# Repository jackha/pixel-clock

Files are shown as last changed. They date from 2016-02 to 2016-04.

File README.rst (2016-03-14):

Pixel Clock
-----------

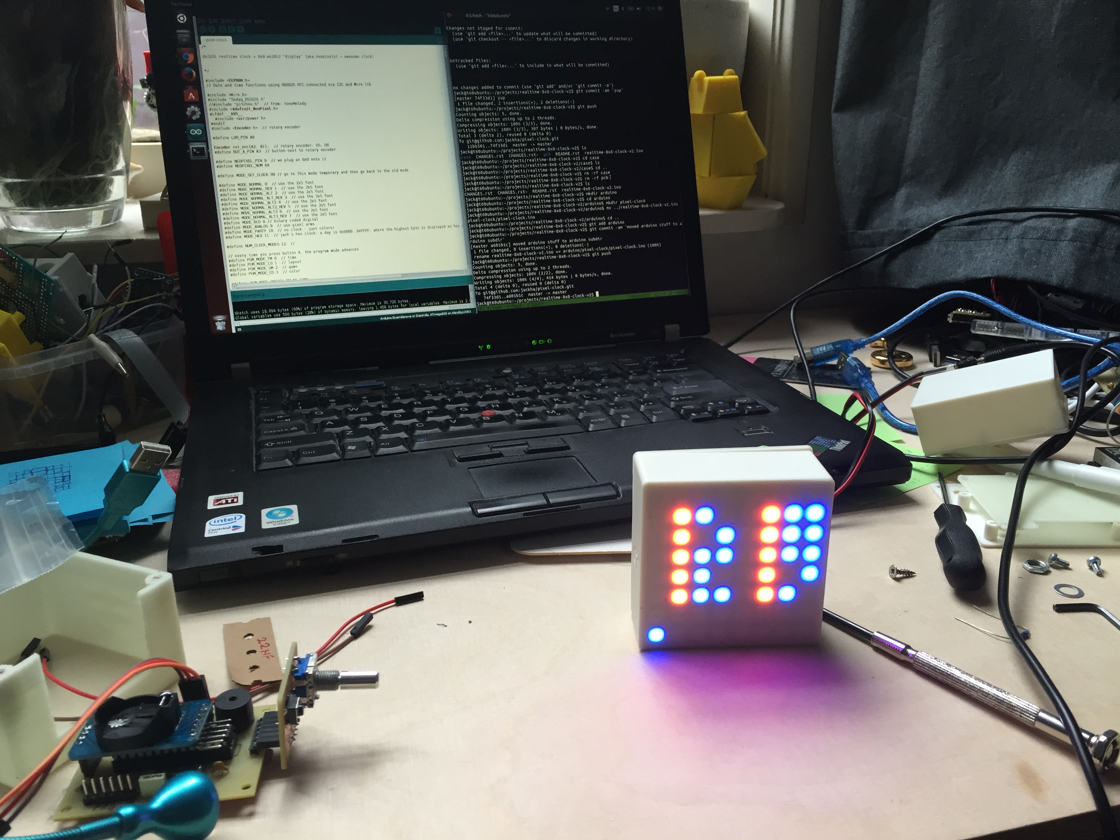
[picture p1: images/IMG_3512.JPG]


A pixel clock with an 8x8 rgb led display based on Arduino.

- Atmega 328 microcontroller
- DS3231 realtime clock module
- ws2812 8x8 LED display aka NeoPixel.
- Control using a rotary encoder /w button.

The case consist of a front and a back part. It is modeled in OpenSCAD.

The pcb is designed in Eagle.

All is work in progress. You can follow the project:

http://jh-interact.blogspot.nl/

http://www.thingiverse.com/thing:1372109

Arduino dependencies
--------------------

Tested and working with these libraries. Many thanks to the authors
for creating and sharing them!!

- Sodaq_DS3231 by keestux, 1.2.0

- Adafruit NeoPixel 1.0.4

- Adafruit GFX Library 1.1.4

- Encoder by Paul Stoffregen 1.4.0

License
-------

Open source hardware and software :-) Please follow my License as I put time
and effort in this project. Thanks!

https://creativecommons.org/licenses/by-nc/3.0/
Attribution-NonCommercial 3.0 Unported (CC BY-NC 3.0)

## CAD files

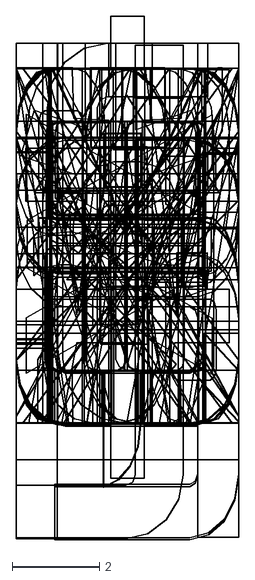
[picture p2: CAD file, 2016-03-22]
case-word-clock/orbitron.dxf
5.08 x 12.0

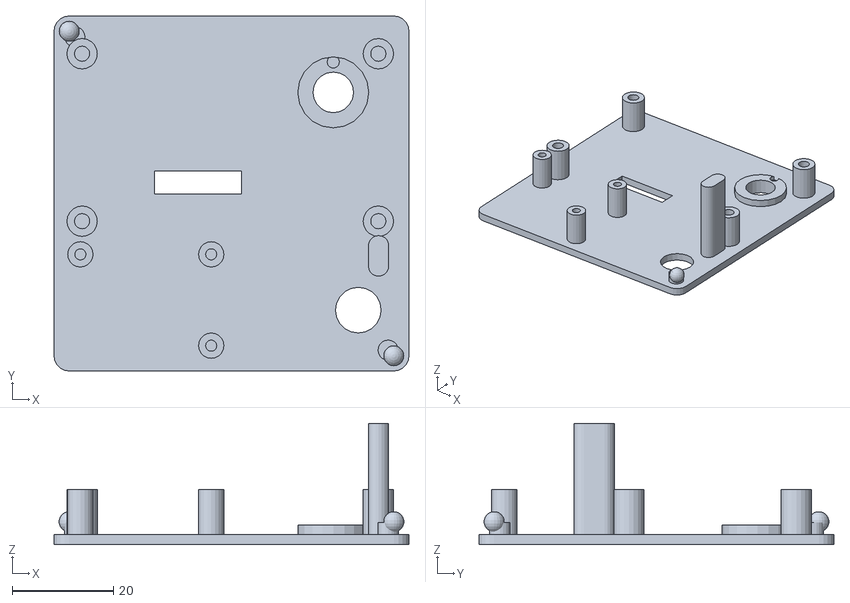
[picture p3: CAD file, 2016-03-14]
case/clock-case3-back.stl
70.0 x 70.0 x 23.9

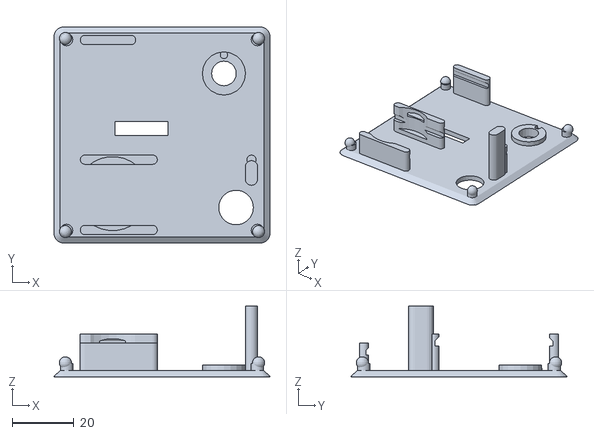
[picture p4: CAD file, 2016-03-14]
case/clock-case4b-07-clearance.stl
70.0 x 70.0 x 22.9

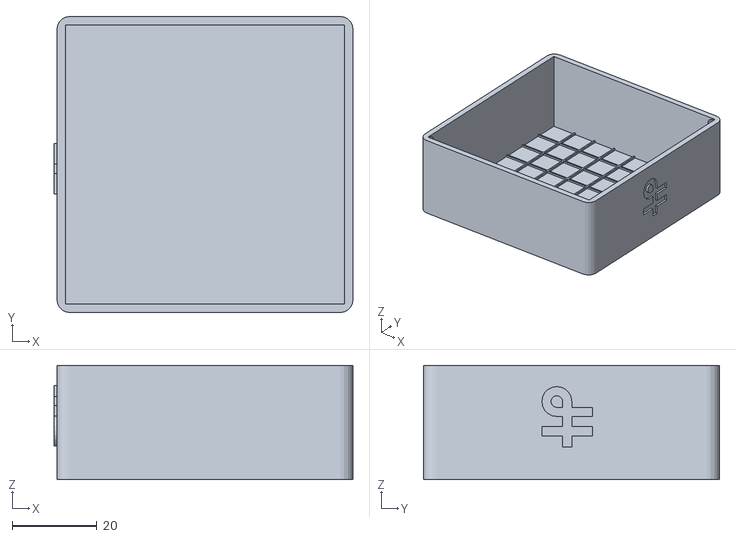
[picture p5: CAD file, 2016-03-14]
case/clock-case3.stl
70.7 x 70.0 x 27.0

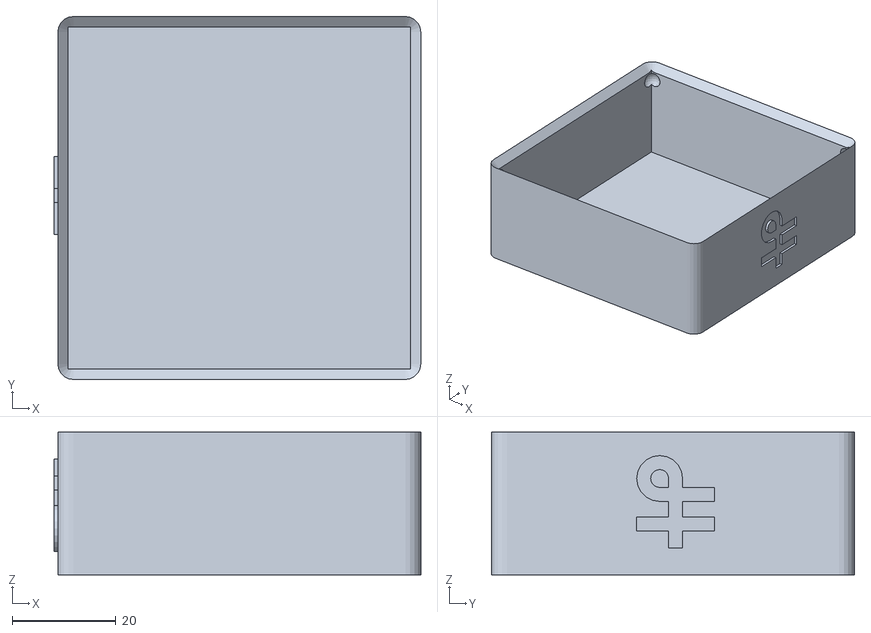
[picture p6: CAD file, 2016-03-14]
case/clock-case4b.stl
70.7 x 70.0 x 27.5

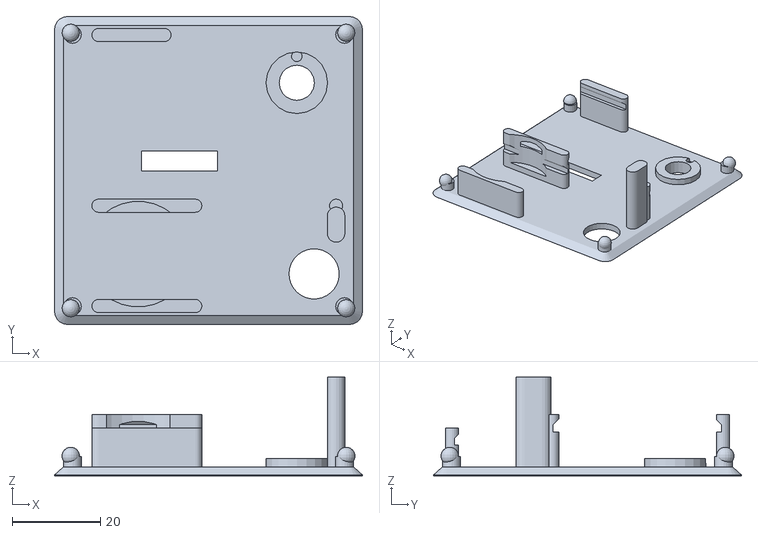
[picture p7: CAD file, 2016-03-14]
case/clock-case4b-back.stl
70.0 x 70.0 x 22.4

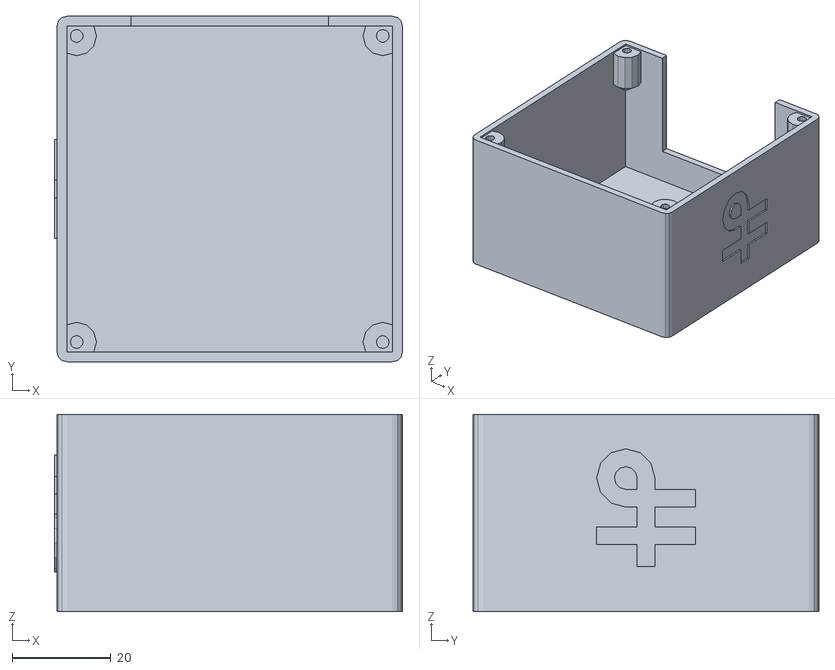
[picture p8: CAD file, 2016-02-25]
case/clock-case.stl
70.5 x 70.0 x 40.0

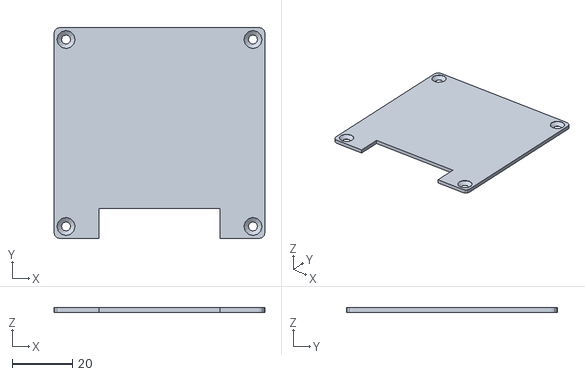
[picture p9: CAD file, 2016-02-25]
case/clock-case-back.stl
70.0 x 70.0 x 1.50

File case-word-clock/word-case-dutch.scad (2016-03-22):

/*
Use this as an extra face plate for the Pixel Clock!
*/

use <Write.scad>

INNER_WIDTH = 70.5;  
INNER_HEIGHT = 70.5;

ROUNDING_R = 4;
ROUNDING_R_INNER = 3;

SIDE_THICKNESS = 1.5;
FRONT_THICKNESS = 1;

OUTER_WIDTH = INNER_WIDTH + 2 * SIDE_THICKNESS;
OUTER_HEIGHT = INNER_HEIGHT + 2 * SIDE_THICKNESS;

DEPTH = 15;

FONT_SIZE = 12;
FONT_SCALE_Y = 0.6;

FONT_X_OFFSET = 4;
FONT_Y_OFFSET = 5;
FONT_Y_SPACING = 8;

LETTERS = [
    "VIJFVOOR", "OVERHALF", "TWEEAALF", "NEGENEEN",
    "DRIEVIER", "VIJFZZES", "ZEVENELF", "ACHTIENZ"];

module rounded_cube(x, y, z, r) {
    translate([r,r,0])
    minkowski() {
        cube([x-2*r, y-2*r, 1]);
        cylinder(r=r, h=z-1);
    }
}

module rounded_cube2(x, y, z, r, x2, y2, r2) {
    hull() {
        translate([r,r,0])
        minkowski() {
            cube([x-2*r, y-2*r, 0.1]);
            cylinder(r=r, h=0.1);
        }

        translate([r2-(x2-x)/2,r2-(y2-y)/2,z-0.2])
        minkowski() {
            cube([x2-2*r2, y2-2*r2, 0.1]);
            cylinder(r=r2, h=0.1);
        }
    
    }
}

difference() {
    rounded_cube(
        OUTER_WIDTH, OUTER_HEIGHT, DEPTH, ROUNDING_R); 

    translate([SIDE_THICKNESS, SIDE_THICKNESS, FRONT_THICKNESS])
    rounded_cube(
        INNER_WIDTH, INNER_HEIGHT, DEPTH, ROUNDING_R_INNER); 

    *rounded_cube2(
        OUTER_WIDTH, OUTER_HEIGHT, DEPTH, ROUNDING_R, 
        INNER_WIDTH, INNER_HEIGHT, ROUNDING_R_INNER);
    
    for (y=[0:7]) {
        translate([OUTER_WIDTH-FONT_X_OFFSET,FONT_Y_OFFSET+y*FONT_Y_SPACING,-0.1])
        mirror([-1,0,0])
        scale([1, FONT_SCALE_Y, 1])
        write(LETTERS[7-y],t=5, h=FONT_SIZE, center=false, font="orbitron.dxf");
    }
}

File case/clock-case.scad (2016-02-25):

use <logo.scad>;

$fn = 12;

SIDE_THICKNESS = 2;
FRONT_THICKNESS = 0.5;
BACK_THICKNESS = 1.5;
DEPTH = 40;

INNER_WIDTH = 66;
OUTER_WIDTH = INNER_WIDTH + 2*SIDE_THICKNESS;
INNER_HEIGHT = 66;
OUTER_HEIGHT = INNER_HEIGHT + 2*SIDE_THICKNESS;

ROUNDING_R = 2;

HOLDER_OUTER_R = 4;
HOLDER_INNER_R = 1.3;
HOLDER_H = 10;

module rounded_cube(x, y, z, r) {
    translate([r,r,0])
    minkowski() {
        cube([x-2*r, y-2*r, 1]);
        cylinder(r=r, h=z-1);
    }
}

module tapped_hole(h1, h2, r1, r2) {
    cylinder(r=r1, h=h1);
    translate([0,0,h1-0.1])
    cylinder(r1=r1, r2=r2, h=h2);
    translate([0,0,h1+h2-0.1])
    cylinder(r=r2, h=10);
}

module base() {
union() {
difference() {
    rounded_cube(OUTER_WIDTH, OUTER_HEIGHT, DEPTH, ROUNDING_R);
    
    translate([SIDE_THICKNESS, SIDE_THICKNESS, FRONT_THICKNESS])
    cube([INNER_WIDTH, INNER_HEIGHT, DEPTH]);
    
    translate([OUTER_WIDTH/2-20, 60, 10])
    cube([40, 50, DEPTH]);

    translate([OUTER_WIDTH - 0.5, OUTER_HEIGHT/2-10, 33])
    rotate([0,90,0])
    logo(5, 20);
}

    translate([2-0.5, OUTER_HEIGHT/2-10, 8])
    rotate([0,-90,0])
    logo(2, 20);

    difference() {
        hull() {
            translate([SIDE_THICKNESS-0.1, SIDE_THICKNESS-0.1, 25])
            cylinder(r=0.1, h=1);
            translate([HOLDER_OUTER_R, HOLDER_OUTER_R, DEPTH-HOLDER_H-0.5])
            cylinder(r=HOLDER_OUTER_R, h=HOLDER_H);
        }
        translate([HOLDER_OUTER_R, HOLDER_OUTER_R, DEPTH-HOLDER_H])
        cylinder(r=HOLDER_INNER_R, h=100);
    }
    difference() {
        hull() {
            translate([OUTER_WIDTH-SIDE_THICKNESS+0.1, SIDE_THICKNESS-0.1, 25])
            cylinder(r=0.1, h=1);
            translate([OUTER_WIDTH-HOLDER_OUTER_R, HOLDER_OUTER_R, DEPTH-HOLDER_H-0.5])
            cylinder(r=HOLDER_OUTER_R, h=HOLDER_H);
        }
        translate([OUTER_WIDTH-HOLDER_OUTER_R, HOLDER_OUTER_R, DEPTH-HOLDER_H])
        cylinder(r=HOLDER_INNER_R, h=100);
    }
    difference() {
        hull() {
            translate([SIDE_THICKNESS-0.1, OUTER_HEIGHT-SIDE_THICKNESS+0.1, 25])
            cylinder(r=0.1, h=1);
            translate([HOLDER_OUTER_R, OUTER_HEIGHT-HOLDER_OUTER_R, DEPTH-HOLDER_H-0.5])
            cylinder(r=HOLDER_OUTER_R, h=HOLDER_H);
        }
        translate([HOLDER_OUTER_R, OUTER_HEIGHT-HOLDER_OUTER_R, DEPTH-HOLDER_H])
        cylinder(r=HOLDER_INNER_R, h=100);
    }
    difference() {
        hull() {
            translate([OUTER_HEIGHT-SIDE_THICKNESS+0.1, OUTER_HEIGHT-SIDE_THICKNESS+0.1, 25])
            cylinder(r=0.1, h=1);
            translate([OUTER_WIDTH-HOLDER_OUTER_R, OUTER_HEIGHT-HOLDER_OUTER_R, DEPTH-HOLDER_H-0.5])
            cylinder(r=HOLDER_OUTER_R, h=HOLDER_H);
        }
        translate([OUTER_WIDTH-HOLDER_OUTER_R, OUTER_HEIGHT-HOLDER_OUTER_R, DEPTH-HOLDER_H])
        cylinder(r=HOLDER_INNER_R, h=100);
    }
    
}
}

SCREW_R1 = 1.5;
SCREW_R2 = 3;

module back() {
   difference() {
        rounded_cube(OUTER_WIDTH, OUTER_HEIGHT, BACK_THICKNESS, ROUNDING_R);
       
       translate([OUTER_WIDTH/2-20, -1, -1])
       cube([40, 11, 10]);
            
       translate([HOLDER_OUTER_R, HOLDER_OUTER_R, -1])
       tapped_hole(r1=SCREW_R1, r2=SCREW_R2, h1=1.2, h2=1.3);

       translate([HOLDER_OUTER_R, OUTER_HEIGHT-HOLDER_OUTER_R, -1])
       tapped_hole(r1=SCREW_R1, r2=SCREW_R2, h1=1.2, h2=1.3);

       translate([OUTER_WIDTH-HOLDER_OUTER_R, HOLDER_OUTER_R, -1])
       tapped_hole(r1=SCREW_R1, r2=SCREW_R2, h1=1.2, h2=1.3);

       translate([OUTER_WIDTH-HOLDER_OUTER_R, OUTER_HEIGHT-HOLDER_OUTER_R, -1])
       tapped_hole(r1=SCREW_R1, r2=SCREW_R2, h1=1.2, h2=1.3);

   }
}

//base();
back();

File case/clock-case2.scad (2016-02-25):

use <logo.scad>;

$fn = 20;

SIDE_THICKNESS = 2;
FRONT_THICKNESS = 0.5;
BACK_THICKNESS = 2;
DEPTH = 27;

INNER_WIDTH = 66;
OUTER_WIDTH = INNER_WIDTH + 2*SIDE_THICKNESS;
INNER_HEIGHT = 66;
OUTER_HEIGHT = INNER_HEIGHT + 2*SIDE_THICKNESS;

ROUNDING_R = 2;

HOLDER_OUTER_R = 4;
HOLDER_INNER_R = 1.3;
HOLDER_H = 10;

module rounded_cube(x, y, z, r) {
    translate([r,r,0])
    minkowski() {
        cube([x-2*r, y-2*r, 1]);
        cylinder(r=r, h=z-1);
    }
}

module tapped_hole(h1, h2, r1, r2) {
    cylinder(r=r1, h=h1);
    translate([0,0,h1-0.1])
    cylinder(r1=r1, r2=r2, h=h2);
    translate([0,0,h1+h2-0.1])
    cylinder(r=r2, h=10);
}

module base() {
union() {
difference() {
    rounded_cube(OUTER_WIDTH, OUTER_HEIGHT, DEPTH, ROUNDING_R);
    
    translate([SIDE_THICKNESS, SIDE_THICKNESS, FRONT_THICKNESS])
    cube([INNER_WIDTH, INNER_HEIGHT, DEPTH]);
    
    translate([OUTER_WIDTH - 0.7, OUTER_HEIGHT/2-7, 22])
    rotate([0,90,0])
    logo(5, 12);
}

    translate([2-0.7, OUTER_HEIGHT/2-7, 8])
    rotate([0,-90,0])
    logo(2, 12);

    difference() {
        hull() {
            translate([SIDE_THICKNESS-0.1, SIDE_THICKNESS-0.1, 25])
            cylinder(r=0.1, h=1);
            translate([HOLDER_OUTER_R, HOLDER_OUTER_R, DEPTH-HOLDER_H-0.5])
            cylinder(r=HOLDER_OUTER_R, h=HOLDER_H);
        }
        translate([HOLDER_OUTER_R, HOLDER_OUTER_R, DEPTH-HOLDER_H])
        cylinder(r=HOLDER_INNER_R, h=100);
    }
    *difference() {
        hull() {
            translate([OUTER_WIDTH-SIDE_THICKNESS+0.1, SIDE_THICKNESS-0.1, 25])
            cylinder(r=0.1, h=1);
            translate([OUTER_WIDTH-HOLDER_OUTER_R, HOLDER_OUTER_R, DEPTH-HOLDER_H-0.5])
            cylinder(r=HOLDER_OUTER_R, h=HOLDER_H);
        }
        translate([OUTER_WIDTH-HOLDER_OUTER_R, HOLDER_OUTER_R, DEPTH-HOLDER_H])
        cylinder(r=HOLDER_INNER_R, h=100);
    }
    *difference() {
        hull() {
            translate([SIDE_THICKNESS-0.1, OUTER_HEIGHT-SIDE_THICKNESS+0.1, 25])
            cylinder(r=0.1, h=1);
            translate([HOLDER_OUTER_R, OUTER_HEIGHT-HOLDER_OUTER_R, DEPTH-HOLDER_H-0.5])
            cylinder(r=HOLDER_OUTER_R, h=HOLDER_H);
        }
        translate([HOLDER_OUTER_R, OUTER_HEIGHT-HOLDER_OUTER_R, DEPTH-HOLDER_H])
        cylinder(r=HOLDER_INNER_R, h=100);
    }
    *difference() {
        hull() {
            translate([OUTER_HEIGHT-SIDE_THICKNESS+0.1, OUTER_HEIGHT-SIDE_THICKNESS+0.1, 25])
            cylinder(r=0.1, h=1);
            translate([OUTER_WIDTH-HOLDER_OUTER_R, OUTER_HEIGHT-HOLDER_OUTER_R, DEPTH-HOLDER_H-0.5])
            cylinder(r=HOLDER_OUTER_R, h=HOLDER_H);
        }
        translate([OUTER_WIDTH-HOLDER_OUTER_R, OUTER_HEIGHT-HOLDER_OUTER_R, DEPTH-HOLDER_H])
        cylinder(r=HOLDER_INNER_R, h=100);
    }


    // holder
        hull() {
            translate([OUTER_HEIGHT-SIDE_THICKNESS+0.1, OUTER_HEIGHT-SIDE_THICKNESS+0.1, DEPTH-3-2])
            cylinder(r=0.1, h=2);
            translate([OUTER_HEIGHT-SIDE_THICKNESS-1, OUTER_HEIGHT-SIDE_THICKNESS-1, DEPTH-1-2])
            cylinder(r=2, h=1);
        }

        hull() {
            translate([OUTER_HEIGHT-SIDE_THICKNESS-1, OUTER_HEIGHT-SIDE_THICKNESS-1, DEPTH-1-2])
            cylinder(r=2, h=1);
            translate([OUTER_HEIGHT-SIDE_THICKNESS+0.1, OUTER_HEIGHT-SIDE_THICKNESS+0.1, DEPTH-2])
            cylinder(r=0.1, h=2);
        }
    
}
}

SCREW_R1 = 1.5;
SCREW_R2 = 3;


MOUNT_SCREW_R = 1.5;  // for base pcb
MOUNT_SCREW_OUTER_R = 3;

MOUNT_SCREW_R2 = 1.1;  // for rtc module
MOUNT_SCREW_OUTER_R2 = 2.5;  // for rtc module

module mounting_tube(h) {
    difference() {
        cylinder(r=MOUNT_SCREW_OUTER_R, h=h);
        translate([0,0,-1])
        cylinder(r=MOUNT_SCREW_R, h=h+2);
    }
}

module pcb_mounting_tubes(h) {
    translate([0.1*25.4, 0.1*25.4, 0])
    mounting_tube(h);

    translate([2.4*25.4, 0.1*25.4, 0])
    mounting_tube(h);

    translate([0.1*25.4, 1.4*25.4, 0])
    mounting_tube(h);

    translate([2.4*25.4, 1.4*25.4, 0])
    mounting_tube(h);

    translate([(2.5-0.45) * 25.4, 1.1*25.4, 0])
    cylinder(r=7, h=2);
}

PRG_MARGIN = 1;

module pcb_holes() {
    translate([(2.5-0.45) * 25.4, 1.1*25.4, -10])
    cylinder(r=4, h=50);

    translate([(2.5-0.45) * 25.4, 1.1*25.4 + 6, 2-1])
    cylinder(r=1.2, h=2);

    translate([0.7 * 25.4-PRG_MARGIN, 0.35*25.4-PRG_MARGIN, -10])
    cube([0.6*25.4+2*PRG_MARGIN, 2.54+2*PRG_MARGIN, 15]);
}

module mounting_tube_rtc(h) {
    difference() {
        cylinder(r=MOUNT_SCREW_OUTER_R2, h=h);
        translate([0,0,-1])
        cylinder(r=MOUNT_SCREW_R2, h=h+2);
    }
}

module rtc_mounts(h) {
    translate([-4, 2, 0])
    mounting_tube_rtc(h);

    translate([-29.8, 20, 0])
    mounting_tube_rtc(h);

    translate([-4, 20, 0])
    mounting_tube_rtc(h);
}

HOOK_R = 2;

module back() {
   difference() {
       union() {
           rounded_cube(OUTER_WIDTH, OUTER_HEIGHT, BACK_THICKNESS, ROUNDING_R);
           
           translate([3,27,BACK_THICKNESS-0.1])
           pcb_mounting_tubes(9);

            // support for display
            hull() {
           translate([64,24.7,BACK_THICKNESS-0.1])
           cylinder(r=2, h=DEPTH-5);
           translate([64,20.7,BACK_THICKNESS-0.1])
           cylinder(r=2, h=DEPTH-5);
            }
                
           translate([35,3,BACK_THICKNESS-0.1])
           rtc_mounts(9);

           // corner hook thing
            translate([0.3,-0.3,0])  // allow some clearance for touching side
            difference() {

           translate([HOOK_R+SIDE_THICKNESS+0.1, OUTER_HEIGHT-HOOK_R-SIDE_THICKNESS-0.1, BACK_THICKNESS-0.1])
           cylinder(r=HOOK_R, h=9);

        union() {
        hull() {
            translate([SIDE_THICKNESS-0.1, OUTER_HEIGHT-SIDE_THICKNESS+0.1, BACK_THICKNESS])
            cylinder(r=0.1, h=2);
            translate([SIDE_THICKNESS+1, OUTER_HEIGHT-SIDE_THICKNESS-1, BACK_THICKNESS+2])
            cylinder(r=2, h=1);
        }

        hull() {
            
            translate([SIDE_THICKNESS+1, OUTER_HEIGHT-SIDE_THICKNESS-1, BACK_THICKNESS+2])
            cylinder(r=2, h=1);
               
        translate([SIDE_THICKNESS-0.1, OUTER_HEIGHT-SIDE_THICKNESS+0.1, BACK_THICKNESS+3+1])
            cylinder(r=.1, h=2);
        
            }
        }
       }
   } // union
       
       translate([3,27,BACK_THICKNESS-0.1])
       pcb_holes();
       
       //pwr connector
       translate([60,12,-1])
       cylinder(r=4.5,h=10);
       
        // screw hole
       translate([0,0,1.3])
       mirror([0,0,1])
       translate([OUTER_WIDTH-HOLDER_OUTER_R, HOLDER_OUTER_R, -1])
       tapped_hole(r1=SCREW_R1, r2=SCREW_R2, h1=1.2, h2=1.3);

   }
}

//base();
back();

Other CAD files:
case/clock-case2.stl
case/clock-case2-back.stl
case/clock-case3.scad
case-word-clock/Write.scad
case/clock-case4b.scad
case/knob.scad
case/logo.scad

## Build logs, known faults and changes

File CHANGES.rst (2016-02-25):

v2
--

- Added OpenSCAD files for the case

- Added eagle files version 3p.

- Use eeprom to save and load

  - layout mode

  - used colors

- Better colors

- A lot of user friendlyness.

- hex clock

- party mode

- a single button + rotary encoder

v1
--

- Set colors.

- Able to set clock on the interface.

- Prototype game (Frogger).

- BCD clock

- 'Normal' numeric clock

- Modes: TM (time), LO (layout), GM (game), CO (color)

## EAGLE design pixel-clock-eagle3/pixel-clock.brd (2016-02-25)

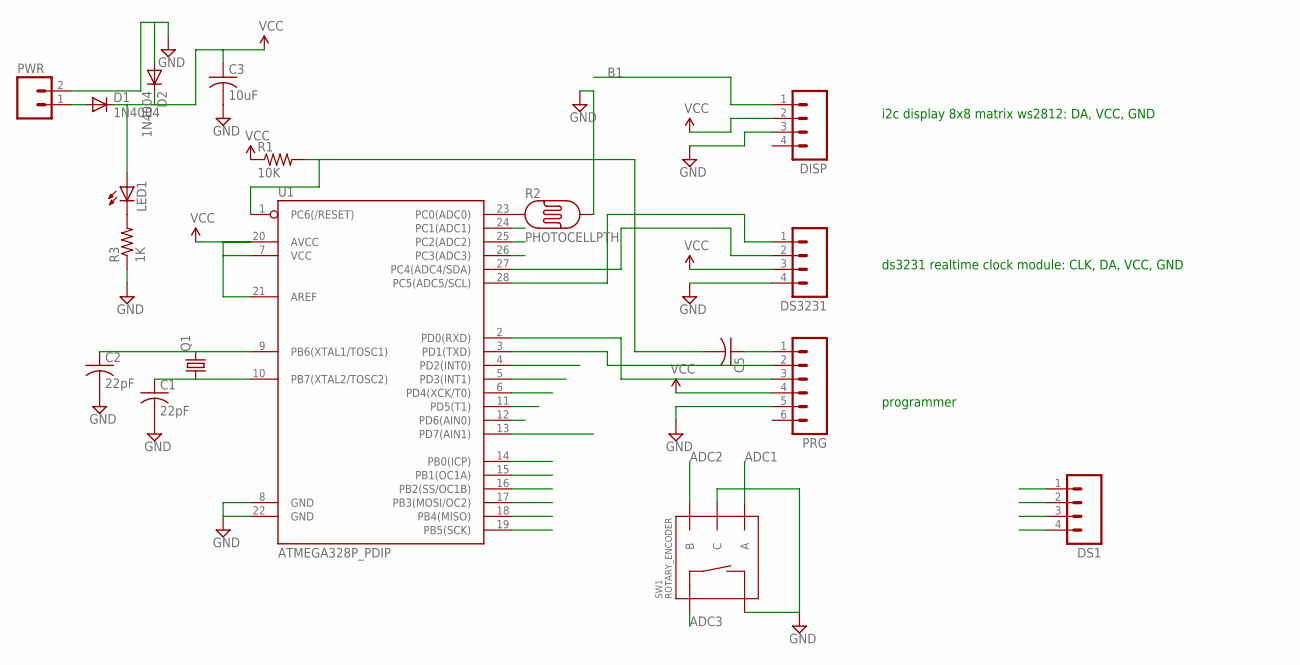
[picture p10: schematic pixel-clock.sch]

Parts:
C1, C2: 22pF; C050-024X044
C3: 10uF; C025-025X050
C5: C-US025-025X050; C025-025X050
D1, D2: 1N4004; DO41-10
DISP: M04PTH; 1X04
DS1, DS3231: M04PTH; 1X04
LED1: LED3MM
PRG: M06SILK_FEMALE_PTH; 1X06
PWR: M02PTH3; 1X02_LONGPADS
Q1: CRYSTALHC49S; HC49/S
R1: 10K; 0207/9
R2: PHOTOCELLPTH; PHOTOCELL
R3: 1K; 0207/9
SW1: ROTARY_ENCODER; ROTARY_ENC_PLAIN
U1: ATMEGA328P_PDIP; DIL28-3

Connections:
ADC1: SW1.A, U1.24 (PC1(ADC1))
ADC2: SW1.B, U1.25 (PC2(ADC2))
ADC3: SW1.SW+, U1.26 (PC3(ADC3))
B0: DS1.1, U1.14 (PB0(ICP))
B1: DISP.1, U1.15 (PB1(OC1A))
B2: U1.16 (PB2(SS/OC1B))
B3: U1.17 (PB3(MOSI/OC2))
B4: U1.18 (PB4(MISO))
B5: U1.19 (PB5(SCK))
D0: PRG.3, U1.2 (PD0(RXD))
D1: PRG.2, U1.3 (PD1(TXD))
D2: U1.4 (PD2(INT0))
D3: U1.5 (PD3(INT1))
D4: U1.6 (PD4(XCK/T0))
D5: U1.11 (PD5(T1))
D6: DS1.3, U1.12 (PD6(AIN0))
D7: DS1.2, U1.13 (PD7(AIN1))
GND: C1.2, C2.2, C3.2, D2.A, DISP.3, DS1.4, DS3231.4, PRG.5, PWR.2, R2.2, R3.1, SW1.C, SW1.SW-, U1.8 (GND), U1.22 (GND)
unnamed: DS3231.1, U1.28 (PC5(ADC5/SCL))
unnamed: DS3231.2, U1.27 (PC4(ADC4/SDA))
unnamed: R2.1, U1.23 (PC0(ADC0))
unnamed: C2.1, Q1.2, U1.9 (PB6(XTAL1/TOSC1))
unnamed: C1.1, Q1.1, U1.10 (PB7(XTAL2/TOSC2))
unnamed: D1.A, PWR.1
unnamed: LED1.K (C), R3.2
unnamed: C5.1, PRG.1
unnamed: C5.2, R1.2, U1.1 (PC6(/RESET))
VCC: C3.1, D1.C, D2.C, DISP.2, DS3231.3, LED1.A, PRG.4, R1.1, U1.7 (VCC), U1.20 (AVCC), U1.21 (AREF)

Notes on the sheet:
i2c display 8x8 matrix ws2812: DA, VCC, GND
ds3231 realtime clock module: CLK, DA, VCC, GND
programmer

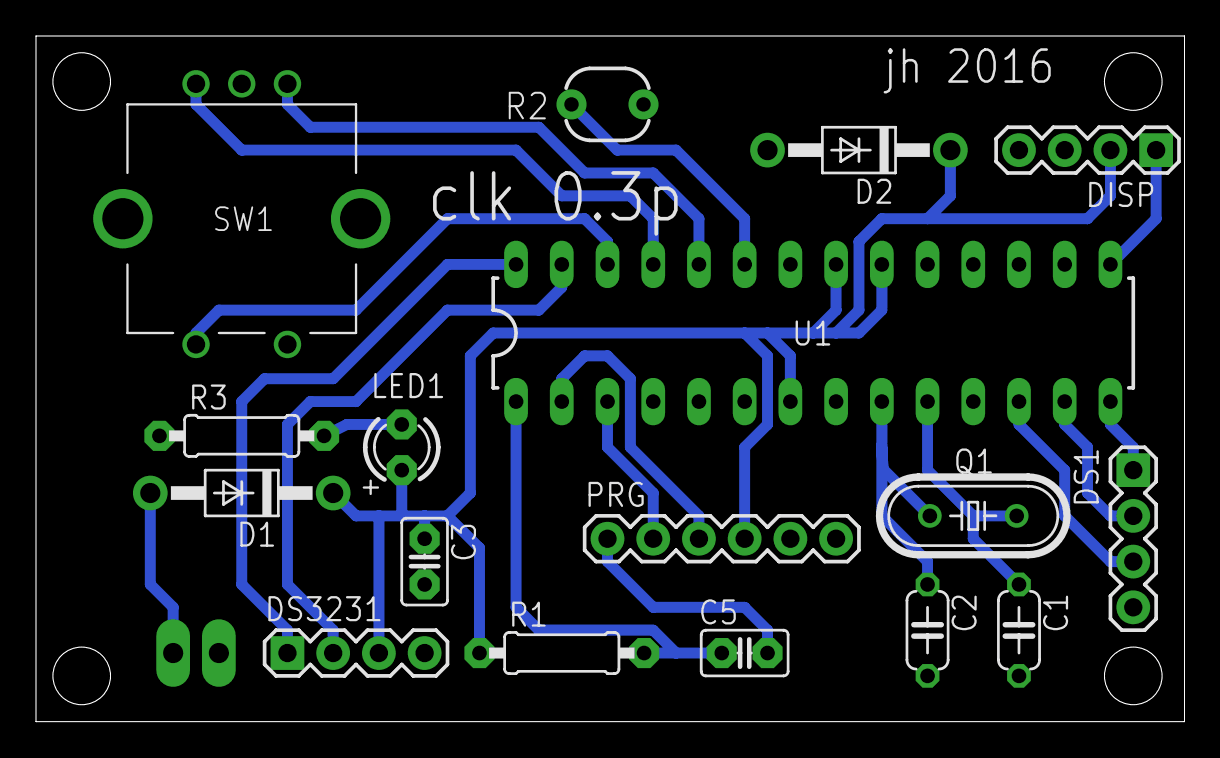
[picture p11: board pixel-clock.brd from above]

Board: 2 copper layers, 63.8 x 38.1 mm, 18 parts (0 on the bottom side), 20 nets.

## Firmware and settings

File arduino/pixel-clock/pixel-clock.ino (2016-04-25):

/*

ds3231 realtime clock + 8x8 ws2812 "display" (aka neopixels) = awesome clock!


*/

#include "font.h"
#include "bitmap.h"
#include "table.h"

#include <EEPROM.h>

// Date and time functions using RX8025 RTC connected via I2C and Wire lib
#include <Wire.h>
#include "Sodaq_DS3231.h"
//#include "pitches.h"  // from: toneMelody
#include <Adafruit_NeoPixel.h>
#ifdef __AVR__
  #include <avr/power.h>
#endif
#include <Encoder.h>  // rotary encoder

#define LDR_PIN A0

Encoder rot_enc(A2, A1);  // rotary encoder: D5, D6
#define BUT_A_PIN A3  // button next to rotary encoder

#define NEOPIXEL_PIN 9  // we plug an 8x8 onto it
#define NEOPIXEL_NUM 64

#define MODE_SET_CLOCK 99 // go to this mode temporary and then go back to the old mode 

#define MODE_NORMAL 0  // use the 2x5 font
#define MODE_NORMAL_REV 1  // use the 2x5 font
#define MODE_NORMAL_ALT 2  // use the 2x5 font
#define MODE_NORMAL_ALT_REV 3  // use the 2x5 font
#define MODE_NORMAL_ALT2 4  // use the 2x5 font
#define MODE_NORMAL_ALT2_REV 5  // use the 2x5 font
#define MODE_NORMAL_ALT3 6  // use the 2x5 font
#define MODE_NORMAL_ALT3_REV 7  // use the 2x5 font
#define MODE_BCD 8 // binary coded digital 
#define MODE_ANALOG 9  // use pixel arms
#define MODE_PARTY 10  // no clock - just colors!
#define MODE_HEX 11  // jack's hex clock: a day is 0x0000..0xFFFF, where the highest byte is displayed as hex and lowest as bits
#define MODE_GAME_OF_LIFE 12  // conways game of life
#define MODE_4X4 13  // conways game of life
#define MODE_WORD 14  // word clock
#define MODE_ROBOT 15

#define NUM_CLOCK_MODES 16  //

// every time you press button A, the program mode advances
#define PGM_MODE_TM 0  // time
#define PGM_MODE_LO 1  // layout
#define PGM_MODE_GM 2  // game
#define PGM_MODE_CO 3  // color
#define PGM_MODE_BR 4  // brightness

#define PGM_MODE_TE 5  // tetris

#define PGM_MODE_SWITCH_DELAY 1000

// in tm mode, every b press advances the time edit mode
#define PGM_TM_NONE 0
#define PGM_TM_HOUR 1
#define PGM_TM_MINUTE 2

#ifdef __AVR__
 #include <avr/io.h>
 #include <avr/pgmspace.h>
#elif defined(ESP8266)
 #include <pgmspace.h>
#else
 #define PROGMEM
#endif

struct RGB {
   byte   r;
   byte   g;
   byte   b;

   byte h;  // hue, for memory purposes only
   byte s;  // saturation
   byte l;  // luminosity
};

struct RGB col_a; 
struct RGB col_b; 

long enc_pos  = -999;  // rotary encoder position
// for colors
long neg_enc_pos  = -999;  // rotary encoder position
long pos_enc_pos  = -999;  // rotary encoder position
volatile long new_enc_pos = -999;
volatile long old_enc_pos = -999;  // detection of movement
uint16_t fast_counter = 0;  // just cycles, for use in timing / moving stuff other than seconds

unsigned long start_approx_millis_time = 0;
unsigned long approx_millis = 0;  // approximate millis

// game of life in RGB! 0 is current buffer, 1 is future
byte game_of_life[2][3*64];

Adafruit_NeoPixel pixels = Adafruit_NeoPixel(NEOPIXEL_NUM, NEOPIXEL_PIN, NEO_GRB + NEO_KHZ800);


char weekDay[][4] = {"Sun", "Mon", "Tue", "Wed", "Thu", "Fri", "Sat" };
//year, month, date, hour, min, sec and week-day(starts from 0 and goes to 6)
//writing any non-existent time-data may interfere with normal operation of the RTC.
//Take care of week-day also.
//DateTime dt(2016, 2, 10, 15, 18, 0, 5);


// notes in the melody:
int melody[] = {
//  NOTE_C4, NOTE_G3, NOTE_G3, NOTE_A3, NOTE_G3, 0, NOTE_B3, NOTE_C4
   35, 100, 200, 60, 32, 76, 250, 0
};

// note durations: 4 = quarter note, 8 = eighth note, etc.:
int noteDurations[] = {
  4, 8, 8, 4, 4, 4, 4, 4
};

int clock_mode = MODE_NORMAL;
int last_clock_mode = MODE_NORMAL;
int pgm_mode = PGM_MODE_LO;

int pgm_mode_tm_state = PGM_TM_NONE;
int hour_inc = 0;  // increase/decrease hour because we want to change it - is auto modded (%)
int minute_inc = 0;

int last_but_a_val = HIGH;
int last_but_b_val = HIGH;
int but_a_val = HIGH;
int but_b_val = HIGH;
int but_counter = 0;

int color_idx = 0;
int tmp_int;

uint16_t ldr_value;
uint16_t brightness;
uint16_t brightness_offset;
int brightness_target;

uint32_t last_action_ts;  // when was the last action? too long -> go back to layout mode

#define TETRIS_SIZE_X 8
#define TETRIS_SIZE_Y 10
byte tetris_playfield[TETRIS_SIZE_Y*TETRIS_SIZE_X]; // we use the 'tetris index' below for its contents, 255 is empty.


#define TETRIS_I 0
#define TETRIS_J 1
#define TETRIS_L 2
#define TETRIS_O 3
#define TETRIS_S 4
#define TETRIS_T 5
#define TETRIS_Z 6
#define TETRIS_EMPTY 255

// RGB colors in order of appearance
static const unsigned char tetris_colors[] PROGMEM = {
  0x00, 0xff, 0xff,  // I, cyan
  0xff, 0x00, 0x00,  // J, blue
  0xff, 0x80, 0x00,  // L, orange
  0xff, 0xff, 0x00,  // O, yellow
  0x00, 0xff, 0x00,  // S, green
  0xa0, 0x20, 0xf0,  // T, purple
  0xff, 0x00, 0x00,  // Z, red
};

static const unsigned char tetris_blocks[] PROGMEM = {
// I
  0b0000,
  0b1111,
  0b0000,
  0b0000,

  0b0010,
  0b0010,
  0b0010,
  0b0010,

  0b0000,
  0b0000,
  0b1111,
  0b0000,

  0b0100,
  0b0100,
  0b0100,
  0b0100,

// J
  0b1000,
  0b1110,
  0b0000,
  0b0000,

  0b0110,
  0b0100,
  0b0100,
  0b0000,

  0b0000,
  0b1110,
  0b0010,
  0b0000,

  0b0100,
  0b0100,
  0b1100,
  0b0000,

// L
  0b0100,
  0b0100,
  0b0110,
  0b0000,

  0b0000,
  0b1110,
  0b1000,
  0b0000,

  0b1100,
  0b0100,
  0b0100,
  0b0000,

  0b0010,
  0b1110,
  0b0000,
  0b0000,
// O
  0b0110,
  0b0110,
  0b0000,
  0b0000,

  0b0110,
  0b0110,
  0b0000,
  0b0000,

  0b0110,
  0b0110,
  0b0000,
  0b0000,

  0b0110,
  0b0110,
  0b0000,
  0b0000,

// S
  0b0110,
  0b1100,
  0b0000,
  0b0000,

  0b0100,
  0b0110,
  0b0010,
  0b0000,

  0b0000,
  0b0110,
  0b1100,
  0b0000,

  0b1000,
  0b1100,
  0b0100,
  0b0000,

// T
  0b0100,
  0b1110,
  0b0000,
  0b0000,

  0b0100,
  0b0110,
  0b0100,
  0b0000,

  0b0000,
  0b1110,
  0b0100,
  0b0000,

  0b0100,
  0b1100,
  0b0100,
  0b0000,

// Z
  0b1100,
  0b0110,
  0b0000,
  0b0000,

  0b0010,
  0b0110,
  0b0100,
  0b0000,

  0b0000,
  0b1100,
  0b0110,
  0b0000,

  0b0100,
  0b1100,
  0b1000,
  0b0000,
};

void reset_tetris() {
  for (int y=0; y<TETRIS_SIZE_Y; y++) {
    for (int x=0; x<TETRIS_SIZE_X; x++) {
      tetris_playfield[y*TETRIS_SIZE_X+x] = TETRIS_EMPTY;
    }
  }
}

// block 0..6, rotation 0..3
// return true if collision or out of bounds, false if ok
boolean tetris_check_collision(int x_, int y_, int block, int rotation) {
  byte tetromino_row;
  int tetromino_offset = block*16 + (rotation % 4)*4;
  byte xx, yy;
  for (int y=0; y<4; y++) {
    tetromino_row = pgm_read_byte(tetris_blocks+tetromino_offset+y);
    for (int x=0; x<4; x++) {
      if ((tetromino_row & 0b1) > 0) {
        xx = 3 - x + x_;
        yy = y + y_;
        if ((xx >= 0) && (xx < TETRIS_SIZE_X) && (yy >= 0) && (yy < TETRIS_SIZE_Y)) {
          //set_pixel(xx + yy * 8, r, g, b, brightness);
          if (tetris_playfield[yy*TETRIS_SIZE_X+xx] != TETRIS_EMPTY) {
            return true;
          }
        } else {
          return true;  // one of the blocks is out of bounds
        }
      }
      tetromino_row = tetromino_row >> 1;
    }
  }
  return false;
}

// display playfield, special function for 8x8 display
// hope this is fast
void tetris_display(int x_offset, int y_offset, int brightness) {
  byte r, g, b;
  byte tetromino;
  for (int y=0; y<8; y++) {
    for (int x=0; x<8; x++) {
      tetromino = tetris_playfield[(y+y_offset)*8+x+x_offset];
      if (tetromino != TETRIS_EMPTY) {
        r = pgm_read_byte(tetris_colors + 3 * tetromino + 0);
        g = pgm_read_byte(tetris_colors + 3 * tetromino + 1);
        b = pgm_read_byte(tetris_colors + 3 * tetromino + 2);

        set_pixel(y*8+x, r, g, b, brightness);  
      }
    }
  }
}

// just 'plot' the piece in place, no collision check
void tetris_place_tetromino(int x_, int y_, int block, int rotation) {
  byte tetromino_row;
  int tetromino_offset = block*16 + (rotation % 4)*4;
  byte xx, yy;
  for (int y=0; y<4; y++) {
    tetromino_row = pgm_read_byte(tetris_blocks+tetromino_offset+y);
    for (int x=0; x<4; x++) {
      if ((tetromino_row & 0b1) > 0) {
        xx = 3 - x + x_;
        yy = y + y_;
        if ((xx >= 0) && (xx < TETRIS_SIZE_X) && (yy >= 0) && (yy < TETRIS_SIZE_Y)) {
          tetris_playfield[yy*TETRIS_SIZE_X+xx] = block;
        }
      }
      tetromino_row = tetromino_row >> 1;
    }
  }  
}

void tetris() {
  reset_tetris();
  int block = TETRIS_S;
  int rotation = 1;
  int x = 3;
  int y = 0;
  boolean game_over = false;
  long int current_millis = millis();
  long int next_move_millis;
  int block_duration = 500;

  int but_a_val, last_but_a_val;
  long int enc_pos;
  rot_enc.write(0);

  while (!game_over) {
    block = (block + 1) % 7;  // TODO: implement "Random Generator"
    rotation = (rotation + 1) % 4;
    x = 3-rotation;
    y = 0;
    game_over = tetris_check_collision(x, y+1, block, rotation) && (y == 0);
    next_move_millis = current_millis + block_duration;
    while (!tetris_check_collision(x, y+1, block, rotation)) {
      pixels.clear();
      // provide offset of playfield and brightness
      tetris_display(0, 2, 100);
      // convert playfield coordinates to screen coordinates
      display_tetromino(x, y-2, block, rotation, 100);  
      pixels.show();
      current_millis = millis();
      if (current_millis > next_move_millis) {
        y += 1;
        next_move_millis = current_millis + block_duration;
      }
      // game controls
      last_but_a_val = but_a_val;
      but_a_val = digitalRead(BUT_A_PIN);
      enc_pos = new_enc_pos / 4;
      if ((enc_pos < 0) && (!tetris_check_collision(x-1, y, block, rotation))) {
        x -= 1;
        rot_enc.write(0);
      }
      if ((enc_pos > 0) && (!tetris_check_collision(x+1, y, block, rotation))) {
        x += 1;
        rot_enc.write(0);
      }
      if (
        (but_a_val == LOW) && 
        (last_but_a_val == HIGH) && 
        (!tetris_check_collision(x+1, y, block, (rotation + 1) % 4))) {
          
        rotation = (rotation + 1) % 4;
      }
    }
    tetris_place_tetromino(x, y, block, rotation);
    // TODO: check for full lines and shift all
  }
  delay(1000);
}

ISR(TIMER1_COMPA_vect){  //change the 0 to 1 for timer1 and 2 for timer2
    new_enc_pos = rot_enc.read();
}

void setup () 
  {

  cli();//stop interrupts


//set timer1 interrupt at 16*10^6/1024/11
  TCCR1A = 0;// set entire TCCR1A register to 0
  TCCR1B = 0;// same for TCCR1B
  TCNT1  = 0;//initialize counter value to 0
  // set compare match register for 8MHz increments
  OCR1A = 10;// (must be <65536)
  // turn on CTC mode
  TCCR1B |= (1 << WGM12);
  // Set prescaler CS10, CS11 CS12
  //TCCR1B |= (1 << CS10);  // no prescaling  
  //TCCR1B |= (1 << CS11);  // /8  
  //TCCR1B |= (1 << CS10) + (1 << CS11);  // /64  
  //TCCR1B |= (1 << CS12);  // 256  
  TCCR1B |= (1 << CS10) | (1 << CS12);  // 1024  
  //TCCR1B |= (1 << CS12) | (1 << CS11);  // external clock on t1 pin, falling edge
  //TCCR1B |= (1 << CS12) | (1 << CS11) |  (1 << CS10);  // external clock on t1 pin, rising edge
  // enable timer compare interrupt
  TIMSK1 |= (1 << OCIE1A);
  sei();//allow interrupts

    pinMode(BUT_A_PIN, INPUT_PULLUP);
    //pinMode(BUT_B_PIN, INPUT_PULLUP);

    pinMode(LDR_PIN, INPUT_PULLUP);

    Serial.begin(57600);
    
    Wire.begin();
    rtc.begin();
    pixels.begin();

    but_a_val = digitalRead(BUT_A_PIN);
    last_but_a_val = but_a_val;

    read_eeprom();
      rot_enc.write(4*clock_mode);
  // prevent readouts on start
  new_enc_pos = rot_enc.read();
  enc_pos = new_enc_pos;

  init_game_of_life();  

  last_action_ts = rtc.now().getEpoch(); 

// testing tetris stuff
//
//  for (int b=0; b<7; b++) {
//  for (int y=-4; y<9; y++) {
//    pixels.clear();
//   display_tetromino(3, y, b*16 + (y/4)*4, 100);
////   display_tetromino(4, 0, TETRIS_Z + 1*4, 100);
////   display_tetromino(0, 4, TETRIS_I + 0*4, 100);
////   display_tetromino(4, 4, TETRIS_O + 2*4, 100);
//   delay(100);
//   pixels.show();
//  }
//  }
//  delay(1000);
  tetris();
}

uint32_t old_ts;

/***************************************************************************/


void display_big_bitmap(int location_offset_x, int location_offset_y, int bitmap_offset, 
  byte r1, byte g1, byte b1,
  byte r2, byte g2, byte b2,
  byte r3, byte g3, byte b3) 
  {
  byte pixels_value, pix_value;
  byte xx, yy;
  byte r, g, b;
  
  // screen coords
  for (int y=0; y<8; y++) {
    for (int x=0; x<8; x++) {
        // image source location
        xx = x + location_offset_x;
        yy = y + location_offset_y;

        if ((xx < 0) || (xx > 31) || (yy < 0) || (yy > 7)) {
          continue;
        }
        // is slightly inefficient, because most bytes are fetched 4 times, oh well
        pixels_value = pgm_read_byte(big_bitmaps+bitmap_offset+yy*8+xx/4);  
        pix_value = (pixels_value >> (2* (3 - xx % 4))) & 0b11;
        switch(pix_value) {
          case 0:
            //r = r0; g=g0; b=b0; break;
            continue; break;
          case 1:
            r = r1; g=g1; b=b1; break;
          case 2:
            r = r2; g=g2; b=b2; break;
          case 3:
            r = r3; g=g3; b=b3; break;          
        }
        set_pixel(y * 8 + x, r, g, b, brightness);
    }
  }
}


/***************************************************************************/
// normal clock with digits from 'font'
void draw_normal_clock(DateTime dt, RGB col_a, RGB col_b, int y0, int y1, int y2, int y3, int dot_location) {
  draw_single_digit(0, y0, dt.hour() / 10, col_a.r, col_a.g, col_a.b);
  draw_single_digit(2, y1, dt.hour() % 10, col_b.r, col_b.g, col_b.b);
  draw_single_digit(4, y2, dt.minute() / 10, col_a.r, col_a.g, col_a.b);
  draw_single_digit(6, y3, dt.minute() % 10, col_b.r, col_b.g, col_b.b);
  if (dt.second() % 2 == 0) {
    set_pixel(dot_location, col_b.r,col_b.g,col_b.b, brightness);
  }
}
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
void loop () 
{
    DateTime now = rtc.now(); //get the current date-time
    uint32_t ts = now.getEpoch();
    byte pix_trans;
    if (ts != old_ts) {
       start_approx_millis_time = millis();
    }
    approx_millis = millis() - start_approx_millis_time;
    if ((ts - last_action_ts) > 300) {
      // go back to default program mode
      pgm_mode = PGM_MODE_LO;
    }
    if (old_enc_pos != new_enc_pos) {
      // detection of movement
      old_enc_pos = new_enc_pos;
    }

    last_but_a_val = but_a_val;
    but_a_val = digitalRead(BUT_A_PIN);

    ldr_value = analogRead(LDR_PIN);
    //Serial.println(ldr_value);
    // offset of a different LDR
    brightness_target = 600 - int(float(ldr_value) * 0.9) + brightness_offset;
    if (brightness < max(brightness_target, 10)) {
    //if (brightness < max(1023 - ldr_value, 10)) {
      brightness++;
    } else {
      brightness--;
    }
    //Serial.println(max(600 - int(float(ldr_value) * 0.9) + brightness_offset, 10));
    //brightness = 50;  // for taking pictures only!!!

      // button down = entering time set mode
      if (but_a_val == LOW) {
          last_action_ts = ts;
          but_counter += 1;

//          // straight transition
//          pixels.setPixelColor((but_counter-50)/3, pixels.Color(0,5,0));
//          pixels.show();

          for (int i=0; i<64; i++) {
            pix_trans = pgm_read_byte(fill_pattern+i+FILL_PATTERN_1);
            if (pix_trans <= (but_counter-50)/3) {
              pixels.setPixelColor(i, pixels.Color(0,5,0));
            }
          }
          pixels.show();

          if (but_counter > 191+50) {   // approx 2 second press
            if (clock_mode == MODE_SET_CLOCK) {
              // cancel clock set
              clock_mode = last_clock_mode;
              pgm_mode = PGM_MODE_LO;
              pgm_mode_tm_state = PGM_TM_NONE;
              rot_enc.write(0);
              display_bitmap(BITMAP_NO, 4, 0, 0);
            } else {
              // enter set clock
              last_clock_mode = clock_mode;
              clock_mode = MODE_SET_CLOCK;
              pgm_mode = PGM_MODE_TM;
              pgm_mode_tm_state = PGM_TM_HOUR;
              rot_enc.write(now.hour()*4);
              new_enc_pos = now.hour()*4;
              hour_inc = now.hour();
              minute_inc = 0;
              enc_pos = new_enc_pos;
              display_bitmap(BITMAP_TM, 0, 4, 0);
            }
            wait_button_up();
          }
      } else {
            but_counter = 0;
      }

      switch (pgm_mode) {
        case PGM_MODE_TM:  // set time
          if ((last_but_a_val == LOW) && (but_a_val == HIGH)) {  // wait until the button is released
            DateTime dt;
            switch (pgm_mode_tm_state) {
              case PGM_TM_HOUR:
                pgm_mode_tm_state = PGM_TM_MINUTE;
                // save hour
                dt = DateTime(now.year(), now.month(), now.date(), hour_inc, now.minute(), now.second(), now.dayOfWeek());
                rtc.setDateTime(dt); //Adjust date-time as defined 'dt' above 
                rot_enc.write(now.minute()*4);
                new_enc_pos = now.minute()*4;
                minute_inc = now.minute();
                hour_inc = 0;  // it is set now
                //enc_pos = new_enc_pos;
                break;
              case PGM_TM_MINUTE:
                pgm_mode_tm_state = PGM_TM_NONE;
                clock_mode = last_clock_mode;
                // save minute
                dt = DateTime(now.year(), now.month(), now.date(), now.hour(), minute_inc, now.second(), now.dayOfWeek());
                rtc.setDateTime(dt); //Adjust date-time as defined 'dt' above 

                pgm_mode = PGM_MODE_LO;
                display_bitmap(BITMAP_OK, 0, 4, 0);
                delay(PGM_MODE_SWITCH_DELAY);
                pgm_mode_tm_state = PGM_TM_NONE;
                rot_enc.write(0);

                break;
            }
          }
          // encoder readout
          switch (pgm_mode_tm_state) {
            case PGM_TM_HOUR:
              if (new_enc_pos < 0) {
                new_enc_pos += 24*4;
                rot_enc.write(new_enc_pos);
              }
              if (new_enc_pos >= 24*4) {
                new_enc_pos -= 24*4;
                rot_enc.write(new_enc_pos);
              }
              hour_inc = new_enc_pos / 4;                
              break;
            case PGM_TM_MINUTE:
              if (new_enc_pos < 0) {
                new_enc_pos += 60*4;
                rot_enc.write(new_enc_pos);
              }
              if (new_enc_pos >= 60*4) {
                new_enc_pos -= 60*4;
                rot_enc.write(new_enc_pos);
              }
              minute_inc = new_enc_pos / 4;                 
              break;
          }
          break;
        case PGM_MODE_LO:
          // encoder readout
          if (new_enc_pos < 0) {
            new_enc_pos += 4*NUM_CLOCK_MODES;
            rot_enc.write(new_enc_pos);
          }
          clock_mode = (new_enc_pos / 4) % NUM_CLOCK_MODES;
          // button a readout
          if ((last_but_a_val == LOW) && (but_a_val == HIGH)) {
            write_eeprom();
            // go to color mode
            pgm_mode = PGM_MODE_CO;
            rot_enc.write(col_b.h + 256 * (255-col_b.s) / 64);  // calculate the encoder position back from current colors
            enc_pos = new_enc_pos;
            pos_enc_pos = col_b.h + 256 * (255-col_b.s) / 64;
            neg_enc_pos = -col_a.h - 256 * (255-col_a.s) / 64;
            display_colors();
            delay(PGM_MODE_SWITCH_DELAY);
          }
          break;
//        case PGM_MODE_GM:
//          // encoder readout
//          if (new_enc_pos != enc_pos) {
//            game();
//            wait_button_up();
//            rot_enc.write(0);
//            enc_pos = 0;
//            new_enc_pos = 0;
//          }
//          // button a readout
//          if ((last_but_a_val == LOW) && (but_a_val == HIGH)) {
//            pgm_mode = PGM_MODE_CO;
//            rot_enc.write(0);
//            enc_pos = new_enc_pos;
//            pos_enc_pos = 0;
//            neg_enc_pos = 0;
//            display_color_bitmap(BITMAP_CLR_CO);
//            delay(PGM_MODE_SWITCH_DELAY);
//          }
//          break;
        case PGM_MODE_CO:
          // encoder readout
          if (new_enc_pos < 0) {
            set_colors_cont_a2(-new_enc_pos);
            if (new_enc_pos > neg_enc_pos) {
              // we're rotating back
              rot_enc.write(pos_enc_pos);
              new_enc_pos = pos_enc_pos;
            } else {
              neg_enc_pos = new_enc_pos;
            }
          }
          if (new_enc_pos > 0) {
            set_colors_cont_b2(new_enc_pos);
            if (new_enc_pos < pos_enc_pos) {
              rot_enc.write(neg_enc_pos);
              new_enc_pos = neg_enc_pos;
            } else {
              pos_enc_pos = new_enc_pos;
            }
          }
          // button a readout
          if ((last_but_a_val == LOW) && (but_a_val == HIGH)) {
            write_eeprom();
            pgm_mode = PGM_MODE_BR;
            // calculate the encoder position back from current brightness offset
            rot_enc.write(brightness_offset);  
            display_brightness();
            delay(PGM_MODE_SWITCH_DELAY);
          }
          break;
        case PGM_MODE_BR:
          // encoder readout
          if (new_enc_pos < 0) {
            rot_enc.write(0);
            new_enc_pos = 0;
          }
          if (new_enc_pos > 100*4) {
            rot_enc.write(100*4);
            new_enc_pos = 100*4;
          }
          Serial.println(new_enc_pos);
          brightness_offset = new_enc_pos;
          // button a readout
          if ((last_but_a_val == LOW) && (but_a_val == HIGH)) {
            write_eeprom();
            pgm_mode = PGM_MODE_LO;
            rot_enc.write(clock_mode*4);
            enc_pos = new_enc_pos;
            display_bitmap(BITMAP_LO, 0, 0, 200);
            delay(PGM_MODE_SWITCH_DELAY);
          }
          break;
      }
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

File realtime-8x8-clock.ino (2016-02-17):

/*

ds3231 realtime clock + 8x8 ws2812 "display" (aka neopixels) = awesome clock!


*/

// Date and time functions using RX8025 RTC connected via I2C and Wire lib

#include <Wire.h>
#include "Sodaq_DS3231.h"
//#include "pitches.h"  // from: toneMelody
#include <Adafruit_NeoPixel.h>
#ifdef __AVR__
  #include <avr/power.h>
#endif
#include <Encoder.h>  // rotary encoder

Encoder rot_enc(6, 5);  // rotary encoder: D5, D6
#define BUT_A_PIN 8  // button next to rotary encoder
#define BUT_B_PIN 7  // button on rotary encoder

#define LDR_PIN A0

#define NEOPIXEL_PIN 10  // we plug an 8x8 onto it
#define NEOPIXEL_NUM 64

#define MODE_NORMAL 0  // use the 2x5 font
#define MODE_BCD 1 // binary coded digital 
#define MODE_SET_CLOCK 2 // go to this mode temporary and then go back to the old mode 

#define NUM_CLOCK_MODES 2  //

// every time you press button A, the program mode advances
#define PGM_MODE_TM 0  // time
#define PGM_MODE_LO 1  // layout
#define PGM_MODE_GM 2  // game
#define PGM_MODE_CO 3  // color

#define PGM_MODE_SWITCH_DELAY 1000

// in tm mode, every b press advances the time edit mode
#define PGM_TM_NONE 0
#define PGM_TM_HOUR 1
#define PGM_TM_MINUTE 2

#ifdef __AVR__
 #include <avr/io.h>
 #include <avr/pgmspace.h>
#elif defined(ESP8266)
 #include <pgmspace.h>
#else
 #define PROGMEM
#endif

struct RGB {
   byte   r;
   byte   g;
   byte   b;
};

struct RGB col_a; 
struct RGB col_b; 

// 2x5 font, numbers only
static const unsigned char font[] PROGMEM = {
    0b11, 
    0b11, 
    0b11, 
    0b11, 
    0b11,
    
    0b01, 
    0b01, 
    0b01,
    0b01,
    0b01,
    
    0b10, 
    0b01, 
    0b11,
    0b10,
    0b11,
    
    0b11, 
    0b01, 
    0b11,
    0b01,
    0b11,
    
    0b10, 
    0b10, 
    0b11,
    0b01,
    0b01,
    
    0b11, 
    0b10, 
    0b11,
    0b01,
    0b11,
    
    0b01, 
    0b10, 
    0b11,
    0b11,
    0b11,
    
    0b11, 
    0b01, 
    0b01,
    0b01,
    0b01,
    
    0b11, 
    0b11, 
    0b00,
    0b11,
    0b11,
    
    0b11, 
    0b11, 
    0b11,
    0b01,
    0b10
};

#define BITMAP_TM 0
#define BITMAP_LO 8
#define BITMAP_GM 16

static const unsigned char bitmaps[] PROGMEM = {
  0b11101110,
  0b01000100,
  0b01001110,
  0b00000000,
  0b11110011,
  0b10101011,
  0b10101010,
  0b00000011,

  0b10000110,
  0b10001001,
  0b10001001,
  0b11100110,
  0b00000000,
  0b00000000,
  0b00000000,
  0b00000000,

  0b01000110,
  0b10001001,
  0b10101111,
  0b11101001,
  0b00000000,
  0b11110011,
  0b10101010,
  0b10101001,
};

#define BITMAP_CLR_CO 0

static const unsigned char bitmaps_co[] PROGMEM = {
  0x00, 0x00, 0x00,  0x40, 0x00, 0x00,  0x40, 0x00, 0x00,  0x00, 0x00, 0x00,  0x00, 0x00, 0x00,  0x00, 0x00, 0x20,  0x00, 0x00, 0x20,  0x00, 0x00, 0x00,  
  0x40, 0x00, 0x00,  0x00, 0x00, 0x00,  0x00, 0x40, 0x00,  0x00, 0x00, 0x00,  0x00, 0x00, 0x00,  0x00, 0x00, 0x20,  0x00, 0x00, 0x00,  0x00, 0x00, 0x20,  
  0x40, 0x00, 0x00,  0x00, 0x00, 0x00,  0x00, 0x40, 0x00,  0x00, 0x00, 0x00,  0x00, 0x00, 0x00,  0x00, 0x00, 0x20,  0x00, 0x00, 0x00,  0x00, 0x00, 0x20,  
  0x40, 0x00, 0x00,  0x00, 0x00, 0x00,  0x00, 0x40, 0x00,  0x00, 0x00, 0x00,  0x00, 0x00, 0x00,  0x00, 0x00, 0x20,  0x00, 0x00, 0x20,  0x00, 0x00, 0x00,  
  0x40, 0x00, 0x00,  0x00, 0x00, 0x00,  0x00, 0x40, 0x00,  0x00, 0x00, 0x00,  0x00, 0x00, 0x00,  0x00, 0x00, 0x20,  0x00, 0x00, 0x20,  0x00, 0x00, 0x00,  
  0x40, 0x00, 0x00,  0x00, 0x00, 0x00,  0x00, 0x40, 0x00,  0x00, 0x00, 0x00,  0x00, 0x00, 0x00,  0x00, 0x00, 0x20,  0x00, 0x00, 0x00,  0x00, 0x00, 0x20,  
  0x40, 0x00, 0x00,  0x00, 0x00, 0x00,  0x00, 0x40, 0x00,  0x00, 0x40, 0x00,  0x00, 0x40, 0x00,  0x00, 0x00, 0x20,  0x00, 0x00, 0x00,  0x00, 0x00, 0x20,  
  0x00, 0x00, 0x00,  0x40, 0x00, 0x00,  0x40, 0x00, 0x00,  0x00, 0x00, 0x00,  0x00, 0x00, 0x00,  0x00, 0x00, 0x20,  0x00, 0x00, 0x00,  0x00, 0x00, 0x20,  
};

static const unsigned char colors[] PROGMEM = {
  40,  0,  0,   25, 15,  0,
  30, 10,  0,   20, 20,  0,
   0, 40,  0,   20, 20,  0,
   0, 30, 20,    0, 10, 10,
   0,  0, 40,    0, 20, 10,
  20,  0, 30,   20,  0, 10,
  20, 20, 20,   10, 10, 30,
};

#define NUM_COLORS 7


long enc_pos  = -999;  // rotary encoder position
volatile long new_enc_pos = -999;
uint16_t fast_counter = 0;  // just cycles, for use in timing / moving stuff other than seconds

Adafruit_NeoPixel pixels = Adafruit_NeoPixel(NEOPIXEL_NUM, NEOPIXEL_PIN, NEO_GRB + NEO_KHZ800);


char weekDay[][4] = {"Sun", "Mon", "Tue", "Wed", "Thu", "Fri", "Sat" };
//year, month, date, hour, min, sec and week-day(starts from 0 and goes to 6)
//writing any non-existent time-data may interfere with normal operation of the RTC.
//Take care of week-day also.
DateTime dt(2016, 2, 10, 15, 18, 0, 5);


// notes in the melody:
int melody[] = {
//  NOTE_C4, NOTE_G3, NOTE_G3, NOTE_A3, NOTE_G3, 0, NOTE_B3, NOTE_C4
   35, 100, 200, 60, 32, 76, 250, 0
};

// note durations: 4 = quarter note, 8 = eighth note, etc.:
int noteDurations[] = {
  4, 8, 8, 4, 4, 4, 4, 4
};



int clock_mode = MODE_NORMAL;
int last_clock_mode = MODE_NORMAL;
int pgm_mode = PGM_MODE_TM;

int pgm_mode_tm_state = PGM_TM_NONE;
int hour_inc = 0;  // increase/decrease hour because we want to change it - is auto modded (%)
int minute_inc = 0;

int last_but_a_val = HIGH;
int last_but_b_val = HIGH;
int but_a_val = HIGH;
int but_b_val = HIGH;

int color_idx = 0;

uint16_t ldr_value;
uint16_t brightness;

ISR(TIMER1_COMPA_vect){  //change the 0 to 1 for timer1 and 2 for timer2
    new_enc_pos = rot_enc.read();
}

void setup () 
  {

  cli();//stop interrupts
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

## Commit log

2016-02-25 moved arduino stuff to arduino subdir
2016-02-25 added openscad and eagle
    [clock-case-back.stl, clock-case.scad, clock-case.stl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]
2016-03-13 added case 4b
    [clock-case3-back.stl, clock-case3.scad, clock-case3.stl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]
2016-03-13 added knob.scad
    [knob.scad]
2016-03-14 Added first word clock case
    [Write.scad, clock-case4b.scad, knob.scad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]
2016-04-04 now really reset program mode after 5 min
    [pixel-clock.ino]

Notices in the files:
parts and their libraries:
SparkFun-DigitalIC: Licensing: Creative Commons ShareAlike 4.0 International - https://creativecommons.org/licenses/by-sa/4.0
